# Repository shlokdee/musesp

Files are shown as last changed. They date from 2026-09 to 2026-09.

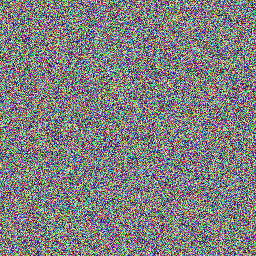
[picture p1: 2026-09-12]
firmware_platformio/musesp/sdcard/wokwi.bmp

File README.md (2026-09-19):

# Musesp: Portable Hi-Fi Digital Audio Player

**Musesp** is an open-source, ultra-portable Digital Audio Player (DAP) built on the ESP32-S3 microcontroller. It delivers high-resolution, uncompressed audio playback (FLAC/WAV) via an I2S DAC, featuring a 2.4" TFT graphical user interface and an isolated 3.0A power delivery system for low-noise audio performance.

---
### Inspiration
* Smartphones have thrown distraction free music listening out of the window, and i would like to bring it back into my life. I could've bought a ready made dap, but where is the fun in that. I have taken inspiration from various ipod restoration channels on youtube, but i wanna do it full DIY in my case.
---

## Technical Features

* **Lossless Audio Streaming:** Dual-core ESP32-S3 (240MHz, 8MB PSRAM) for continuous 24-bit/96kHz audio streaming.
* **Dedicated Hardware DAC:** PCM5102A DAC for clean IEM/headphone driving.
* **UI Navigation:** Hardware SPI ST7789 display paired with dynamic 5-button switch navigation (Play/Pause, Track Next/Prev, Volume +/-).
* **Onboard Storage:** Integrated MicroSD card slot utilization for fast FAT32/exFAT audio library parsing.

---
## Bill of Materials (BOM)

| Component | Description & Usecase | Qty | Unit Price (INR) | Total Price (INR) | Vendor Link |
| :--- | :--- | :---: | :---: | :---: | :--- |
| **ESP32-S3 DevKit (N16R8)** | Dual-core 240MHz MCU with integrated MicroSD slot, 8MB PSRAM & 16MB Flash. Handles audio buffering and display UI directly. | 1 | ₹839 | ₹839 | [Robu.in Link](https://robu.in/product/esp32-s3-devkit-esp32-s3-wroom-1-n16r8/) |
| **PCM5102A I2S DAC Module** | 32-bit / 384kHz Hi-Fi DAC with ~112dB SNR & integrated charge pump. Directly drives 16–32Ω IEMs via 3.5mm jack. | 1 | ₹450 | ₹450 | [Hubtronics Link](https://hubtronics.in/pcm5102-i2s-digital-audio-dac-decoder-module) |
| **2.4" SPI TFT Display (240x320)** | Full-color ST7789 SPI display for album art, track details, playback controls, and menu navigation. | 1 | ₹649 | ₹649 | [Robu.in Link](https://robu.in/product/2-4-inch-spi-interface-240x320-touch-screen-tft-display-module/) |
| **2 PIN WHITE TACT SWITCH C0402** | Switches for navigation and media controls (Play/Pause, Next, Prev, Vol+, Vol-). | 5 | ₹3 | ₹15 | [Robu.in Link](https://robu.in/product/2-pin-white-tact-switch-c0402/) |
| **NOVA 105050 3000mAh 3.7V LiPo Battery** | Single-cell 3.7V LiPo with onboard PCB protection. Delivers ~10–12 hours of continuous playback. | 1 | ₹469 | ₹469 | [Robu.in Link](https://robu.in/product/nova-105050-3000mah-3-7v-micro-lipo-battery-pack/) |
| **TP4056 1A Li-Ion Charger (Mini USB)** | Onboard 1A linear charging module with DW01 IC for over-charge, over-discharge, and short-circuit protection. | 1 | ₹38 | ₹38 | [Robu.in Link](https://robu.in/product/tp4056-1a-li-ion-lithium-battery-charging-module-with-current-protection-mini-usb/) |
| **SPDT Mini Slide Switch** | Physical hard toggle switch  | 1 | ₹12 | ₹12 | [Robu.in Link](https://robu.in/product-tag/slide-switch/) |
| **3D print** |-|-|₹500|₹500|Robu service|
| **Total Hardware Cost** | **Complete Portable Hi-Fi Player Hardware BOM** | - | — | **₹2972** | — |

31 USD

---

## Enclosure

The enclosure will be 3D printed. Also, this model is based on what models i find on the internet. Dimensions of various components may differ physically. This will be taken care of later.

[Onshape Model](https://cad.onshape.com/documents/264e94d89a18f09f2a1ea4bf/w/94a54fd68cc89b6b12089792/e/665c9b9603db8db9ac692859)
Screenshot From 2026-09-16 11-54-38

---
## Schematic


(sd card reader is included in the back of the devboard im using, so no connections for that...)



## Steps to Build:

1. Connect the components using the schematic
2. 3d Print the enclosure
3. Aligh the items using the onshape model given
4. Use 3 10 mm m3 screws to secure the back plate, and 1 3 mm m3 screw to secure the last hole on the display
5. Put the sd card with all your mp3 files
6. Flash the firmware from the platformio project
7. Youre done!!!

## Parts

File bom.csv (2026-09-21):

Component | Description & Usecase | Qty | Unit Price (INR) | Total Price (INR) | Vendor Link
ESP32-S3 DevKit (N16R8) | Dual-core 240MHz MCU with integrated MicroSD slot, 8MB PSRAM & 16MB Flash. Handles audio buffering and display UI directly. | 1 | ₹839 | ₹839 | https://robu.in/product/esp32-s3-devkit-esp32-s3-wroom-1-n16r8/
PCM5102A I2S DAC Module | 32-bit / 384kHz Hi-Fi DAC with ~112dB SNR & integrated charge pump. Directly drives 16–32Ω IEMs via 3.5mm jack. | 1 | ₹450 | ₹450 | https://hubtronics.in/pcm5102-i2s-digital-audio-dac-decoder-module
2.4" SPI TFT Display (240x320) | Full-color ST7789 SPI display for album art, track details, playback controls, and menu navigation. | 1 | ₹649 | ₹649 | https://robu.in/product/2-4-inch-spi-interface-240x320-touch-screen-tft-display-module/
2 PIN WHITE TACT SWITCH C0402 | Switches for navigation and media controls (Play/Pause, Next, Prev, Vol+, Vol-). | 5 | ₹3 | ₹15 | https://robu.in/product/2-pin-white-tact-switch-c0402/
NOVA 105050 3000mAh 3.7V LiPo Battery | Single-cell 3.7V LiPo with onboard PCB protection. Delivers ~10–12 hours of continuous playback. | 1 | ₹469 | ₹469 | https://robu.in/product/nova-105050-3000mah-3-7v-micro-lipo-battery-pack/
TP4056 Li-ion Battery Charger Module with Protection - Micro USB | Onboard 1A linear charging module with DW01 IC for over-charge, over-discharge, and short-circuit protection. | 1 | ₹19 | ₹19 | https://hubtronics.in/tp4056-dw01-fs8205
SPST Rocker switch | turning it on and off! | 1 | ₹14 | ₹14 | https://robu.in/product/spst-rocker-switch-pack-of-3/
3D printing case | - | - | ₹500 | ₹500 | "robu service"
Total Hardware Cost | Plus Shipping | 11 | — | 2955= 31 USD | —

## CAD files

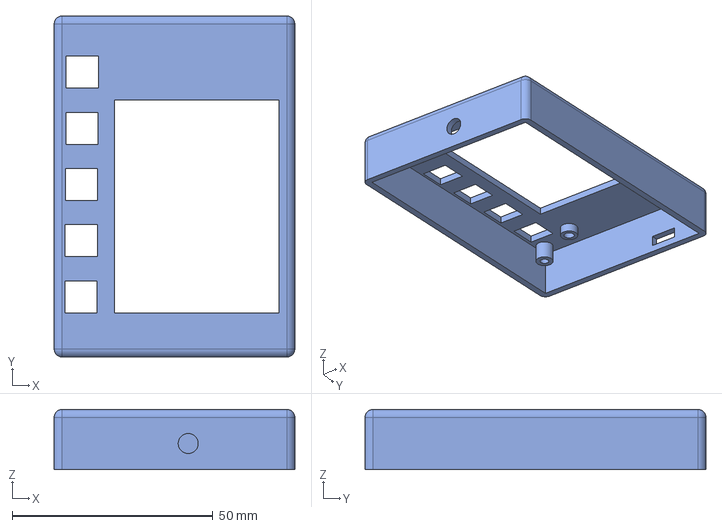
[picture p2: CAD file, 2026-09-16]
enclosure_files/frontplate.step
60.0 x 85.0 x 15.0 mm

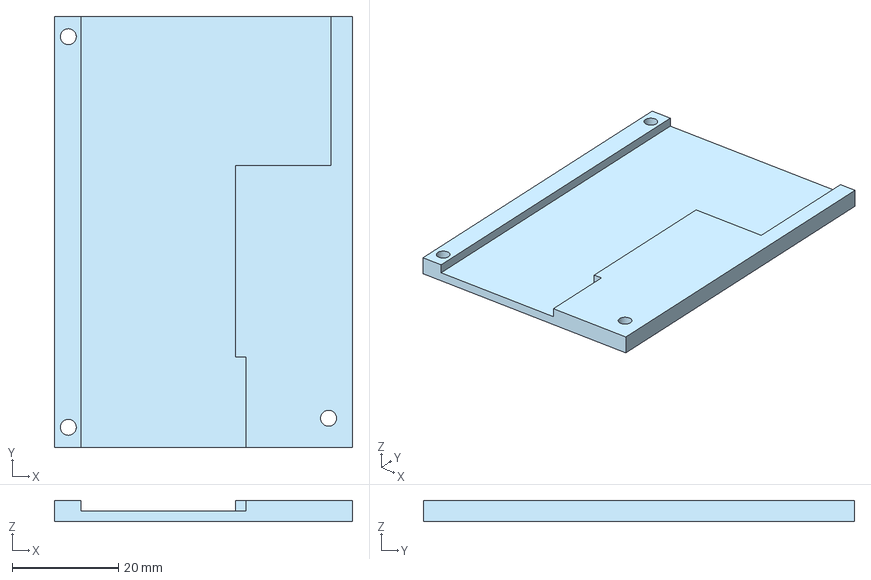
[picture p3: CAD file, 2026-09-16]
enclosure_files/Backplate.step
56.0 x 81.0 x 4.00 mm

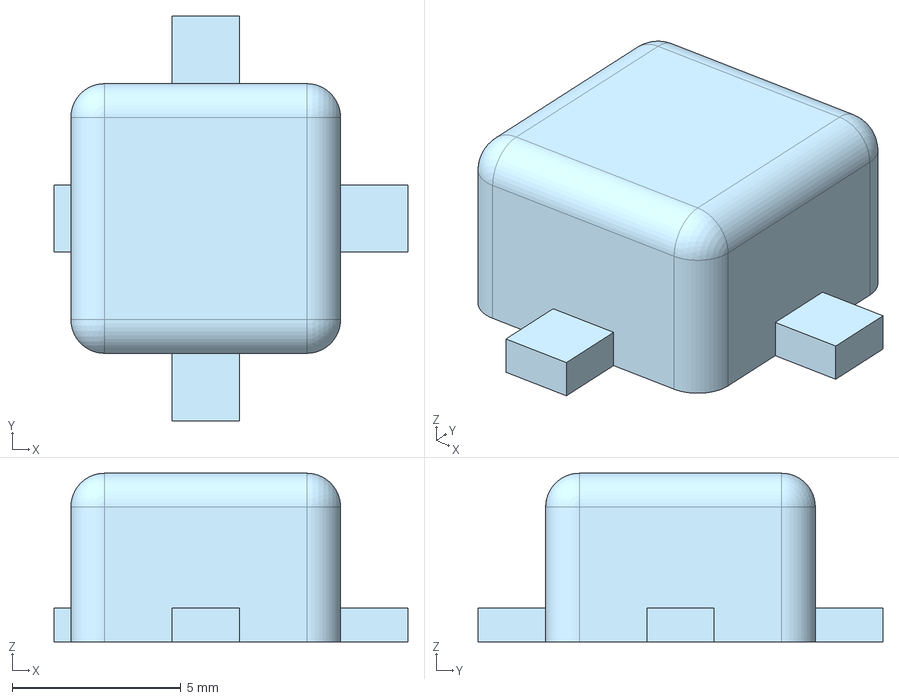
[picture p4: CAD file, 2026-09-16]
enclosure_files/button.step
10.5 x 12.0 x 5.00 mm

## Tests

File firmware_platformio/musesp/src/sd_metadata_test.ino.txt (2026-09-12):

#include "SdFat.h"

#define SPI_SPEED SD_SCK_MHZ(4)
#define CS_PIN 10

SdFat sd;

void readRealMP3Metadata(const char* filepath) {
  SdFile file;

  if (!file.open(filepath, O_READ)) {
    Serial.print("File not found on SD: ");
    Serial.println(filepath);
    return;
  }

  uint32_t fileSize = file.fileSize();
  Serial.println("----------------------------------------");
  Serial.print("File Path : "); Serial.println(filepath);
  Serial.print("File Size : "); Serial.print(fileSize); Serial.println(" bytes");

  // Check for ID3v2 header (first 10 bytes)
  char header[10];
  if (file.read((uint8_t*)header, 10) == 10) {
    if (strncmp(header, "ID3", 3) == 0) {
      Serial.print("Tag Format: ID3v2.");
      Serial.print((int)header[3]);
      Serial.print(".");
      Serial.println((int)header[4]);
    } else {
      Serial.println("Tag Format: No ID3v2 header at file start");
    }
  }

  // Check for ID3v1 footer (last 128 bytes)
  if (fileSize >= 128) {
    file.seekSet(fileSize - 128);
    char footer[128];
    if (file.read((uint8_t*)footer, 128) == 128) {
      if (strncmp(footer, "TAG", 3) == 0) {
        Serial.print("Title     : ");
        for (int i = 3; i < 33 && footer[i] != 0; i++) Serial.print(footer[i]);
        Serial.println();

        Serial.print("Artist    : ");
        for (int i = 33; i < 63 && footer[i] != 0; i++) Serial.print(footer[i]);
        Serial.println();
      } else {
        Serial.println("ID3v1     : No ID3v1 footer found");
      }
    }
  }

  file.close();
}

void setup() {
  Serial.begin(115200);
  while (!Serial) {}

  if (!sd.begin(CS_PIN, SPI_SPEED)) {
    Serial.println("SD card initialization failed!");
    return;
  }

  Serial.println("\n--- Current SD Card Directory ---");
  sd.ls(LS_R | LS_SIZE);

  Serial.println("\n--- Reading File Metadata ---");
  for (int i = 1; i <= 4; i++) {
    char path[32];
    snprintf(path, sizeof(path), "dummy_mp3s/track0%d.mp3", i);
    readRealMP3Metadata(path);
  }
}

void loop() {
}

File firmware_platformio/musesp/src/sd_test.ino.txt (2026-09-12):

#include "SdFat.h"

#define SPI_SPEED SD_SCK_MHZ(4)
#define CS_PIN 10

SdFat sd;
SdFile file;

void setup() {
  Serial.begin(115200);

  if (!sd.begin(CS_PIN, SPI_SPEED)) {
    Serial.println("SD initialization failed!");
    return;
  }

  // Open test.txt for writing (O_CREAT = create if missing, O_TRUNC = overwrite contents)
  if (!file.open("test.txt", O_WRITE | O_CREAT | O_TRUNC)) {
    Serial.println("Failed to open test.txt for writing!");
    return;
  }

  // Write multiple lines of data
  file.println("=== Wokwi SD Card Test File ===");
  for (int i = 1; i <= 10; i++) {
    file.print("Data Entry #");
    file.print(i);
    file.println(" -> Sensor reading: OK");
  }
  file.println("=== End of File ===");

  // Close the file to flush data to virtual storage
  file.close();
  Serial.println("Data successfully written to test.txt!\n");

  // Show directory listing
  Serial.println("Files currently on card:");
  sd.ls(LS_R | LS_SIZE);

  // Read back the contents to confirm
  Serial.println("\nReading test.txt contents back:");
  
}

void loop() {
}

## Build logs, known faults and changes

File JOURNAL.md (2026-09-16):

---
title: "musesp"
author: "f20260342"
description: "An audiophile digital audio player made with esp 32"
created_at: "2026-09-10"
---

# 2026-09-16: Completed the Design
**Total time spent: 30 mins** 
[Lapse Link](https://lapse.hackclub.com/timelapse/JOr6y3ShN6ii)

Finally completed the case design for the musesp...
### Designed the buttons

Designed the buttons and placed them in the assembly...

The button mounting is going to work as follows:
I will solder the buttons on a perf board and cut the perf board acc to the right dimensions. Then ill screw in the perf board in the holes on the front plate. Also, ill use a bigger screw, that goes through the backplate too, so that all of them are secured...


Thats what i did next. Added screw holes to the back plate and aligned them properly




And voila! The case is designed!!!

Next steps: Ship somewhere!!!

# 2026-09-14: Coded a bit more

**Total time spent: 1 hour 30 mins**

Added a bunch more logic to the code. 
First of all, i removed the delay thing, instead replaced it with millis. This will help when i write the music playing function, where i want to continuously play the music, delay wouldve caused gaps in between...



Then I also added what pausing would do. It pauses the whole thing as well as changes the icon. I had an issue where it would constantly refresh the icon every few milliseconds, but i solved it by adding a pause changed variable, which switches the icon every button press.

Then i added a debounce helper, as button pressing and the actions were unpredictable when i was testing it. a debounce helper basically notes only 1 button press down when you press it, or else the esp takes multiple presses per second if you keep holding it for more than a few ms... This also had caused the play button to just play for a few ms and then stop again, all in a single press. The debounce helper added a bit of margin to it.


# 2026-09-13: Simulated the switches and dummy tested the actions

**Total time spent: 1 hour**



Connected the switches in the simulator, and tested some code for the actions (fwd, bwd, pause, etc...) Still have to figure out the sd situation, thinking about writing some untested code that fetches from the sd card, populates a dictionary with the metadata... and then im trying to declare the dictionary as a variable in the code and write all the code based on that...

This is the loop i wrote that displays all the data (i still have to look at the image thing)
Also this delay thing wont work, as ill have to run other processes (like audio playback and list browsing) parallely. 

# 2026-09-13: Designed the case even better

**Total time spent: 1 hour**
[Lapse Link](https://lapse.hackclub.com/timelapse/mgQHt819XnAD)

I solved the fitting problem of the electronics components. I made a thick back plate, and then extrude cut the outlines of the boards... so that they sit into the surface... 

I will later add some clips to fasten the boards in place. But right now, the bards have somewhere to sit. Ive also given a but of snuggle room for the boards, as they can be different size from the ones i found step files of...



I also aligned and added holes for the charging port and 3.5 mm jack... I will probably add some finishing touches like a fillet and stuff, to make it less sharp. but its a later thing



Also adjusted the height so that it is really thin, as well as the clearances are met...
But, this is going to be adjusted later to make space for the battery... 



Im almost done with the design. i will continue with adding buttons later on, and also adding screws for the back plate to fit to the front plate...

The whole body is prolly too thick too, ill reduce the thickness for sure...

# 2026-09-13: Started designing the case

**Total time spent: 1 hour**
[Lapse Link](https://lapse.hackclub.com/timelapse/2ntoext6Lj6C)

I first tried to use fusion 360, but my laptop is slow as hell, so i switched to onshape...

I first downloaded a bunch of step files for the big 3, esp, lcd and the audio driver.


I also designed a face plate and added holes for buttons to pop up

Arranging them in the space was kinda tricky. firstly, the parts within the component had to be grouped, or else they werent moving together in the assembly. secondly, i couldnt remove the header pins of the display board, so the modules are kinda through the header pins, but ill fix it in real life...


Now i have to figure out the mounting thing, i can use bolts for the display and face plate, but something needs to be figured out for the esp and dac. 
Also battery needs to be included, along with carving the 3.5 mm jack and the charging port...

# 2026-09-12: Eureka moment with local wokwi

**Total time spent: 2 hours**

I forgot to Lapse this, but ive got a bunch of screenshots

### I got to know that i can use wokwi locally on vs code!!! 
this heavily reduces the compiling time....
but it took me a while to set up the whole thing...
* I had to install platformio first
* then create a project selecting the right board
* compile the code first, which generates firmware files
* then create a wokwi.toml file that i have to add the firmware file locations
* then copy paste the diagram.json from the online simulator
* then finally run the whole thing...


### Also remade the connections
Got to know that the board has some default spi pins, and the built in sd card is connected to those only...

So i revised the connections, and connected the display too to the same spi pins..

### Tried making the sd card work with vs code
Uploading files to sd card on online version was a premium feature, i thought it would be different here, but i couldnt figure out a way to do it...
I tried a bunch of different methods, like writing data first and then reading it back (this wouldve been just a temporary solution if worked...), making a folder called sd or sdcard and pray that wokwi would recognise it, etc... I didnt find anything on the docs either...



the sd was initialising, but file reading was not working....

# 2026-09-12: Designed the UI

**Total time spent: 1 hour**
[Lapse Link](https://lapse.hackclub.com/timelapse/PfEjHNs3jHrg)

I found this UI builder called lopaka

I used it to design a very basic UI, which was static. and then i can manipulate different stuff using the code... I built it so that its the only screen ill need to design. the songs will be listed in the right grid, and the now playing and buttons are there too....

Then i simulated it in wokwi, altering the lopaka code, and built a moving seeking bar. Ill still have to add some logic to move it according to the song length though.


# 2026-09-12: Simulated a very small part of the firmware

**Total time spent: 1.5 hours**
[Lapse Link](https://lapse.hackclub.com/timelapse/m9FCerOfpstV)

I thought Firmware design would be a piece of cake, ill just stitch together code from various sources and ill be done in a few hours...
but 1.5 hours in, im just done with displaying a small image from the sd to the display :cry:
So here is what i did today: 
### Test the display


I connected the display with the s3 according to the circuit i made yesterday, and started running example code from the libraries. Now the problem was that most of this code was written for Arduino. where the spi lanes area already decided. I didnt know if something like that was there for esp 32 as well. so i spent the fiarst 30 mins in figuring out that i have to declare the spi lanes myself. So i basically perfected the initialisation part, replaced the example code's display initialization with mine, and then run the example. 

I ran a few tests like text display, line display, image display, etc (i forgor to take a ss of this image display without sd card)..

### Test the sd card
Again i ran into problems with spi, and after a whole lot of figuring out, i got to know that you have to keep the same spi lanes for all spi devices. so i did that, and it started working. 


wokwi wont let me upload anything to the sd card, as uploading was a premium feature, so i instead replaced the wokwi's example code where they demonstrated displaying an image from the sd to display via arduino, with my code and circuitry. and it worked. 


I also uploaded the test codes and connections on github.

## Next steps: 
* Update the kicad with new connections
* Write firmware to read files from the sd card and put the album cover onto the display.
* Update the firmware to browse files from the sd card from the display
* Update the firmware to show the whole ui (now playing, control buttons, seeker, etc.)
* Design a case

# 2026-09-11: Figured out the Display and ESP connections using a simulator

**Total time spent: 1 hr**

I used Cirkit Designer IDE to connect, code and simulate the working of the Display with the esp 32 s3 board.



After this, i will start looking into the firmware for the display driving. 

# 2026-09-10: Added a readme and finished up with other small components

**Total time spent: 1 hour**

Made a readme, with project milestones, working plans. I believe moving ahead from here will require some breadboard prototyping, as im having really a hard time judging if things will work the way i want to. So ive decided to submit the project for review, if approved, get the components, try them together, and then move ahead with other stuff like software and enclosure. 
I also completed the bom for the first phase, with battery and charger. it comes out to around 26 usd. 


# 2026-09-10: Figured out the connections for the main 3 modules

**Total time spent: 1 hour**
[Lapse Link](https://lapse.hackclub.com/timelapse/I4MPxc_vWduY)

I looked around on the internet, read the seller specifications and laid out the basic connections for the 3 modules. The s3 variant of esp32 gave me a hard time. This is subject to change, as most of the reiterations on the hardware side is going to happen only after i receive the components. After that, i can actually test out the stuff and make changes. The schematic i made is kinda speculative, as most of the connections were for esp 32 and not s3. 


Next steps: Figure out the additional components, like battery management, buttons, etc. and build the case.

# 2026-09-10: Searched about various components required to build the project

**Total time spent: 2 hours**

I spent some time today researching the core hardware architecture for my portable Hi-Fi audio player, and preparing the basic BOM (essential components right now, others will be added later). The goal is to build an iPod-style player capable of driving sensitive In-Ear Monitors (IEMs) with zero noise or hiss, playing lossless files (WAV/FLAC), and maintaining a fully modular design so components can be swapped out easily.

### Key Decisions & Hardware Reasoning

- **Microcontroller: ESP32-S3 (with PSRAM)**
    
    - _Why:_ Standard microcontrollers like an Arduino Uno dont have the processing power or hardware peripherals for real-time audio decoding. The ESP32 offers native I2S bus support, dual-core processing, and built-in Wi-Fi/Bluetooth. Using an ESP32-S3 with external PSRAM gives the large RAM buffer needed to stream 16-bit/24-bit FLAC files off an SD card without playback stutter as well as render the album art properly. Also the one i put in the BOM has a SD card slot as well.
        

- **DAC Module: TI PCM5102A (Over UDA1334A or MAX98357A)**
    
    - _Why:_ IEMs are extremely sensitive to background hiss. The other dac modules i looked at were either too high powered, or too low quality
        

- **Display: ST7789 2.0"/2.4" SPI TFT LCD (240x320)**
    
    - _Why:_ Other OLEDs (like the SSD1306) are too small to render track lists and album art nicely. This is perfectly sized, works over SPI.
      

### What's Next?

Now that the hardware strategy is locked in, Im going to start looking at connections and start building the basic 3d structure of the player. Im also going to add other components like battery, charging circuit, etc to the BOM

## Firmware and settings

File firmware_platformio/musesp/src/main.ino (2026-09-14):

#include <SPI.h>
#include <FS.h>
#include <SD.h>

#include <Adafruit_GFX.h>
#include <Adafruit_ILI9341.h>
#include "ui.h"
#include "debounce_helper.h"
#include "audio_player.h"


// ESP32-S3 to ILI9341 wiring in this project
#define TFT_CS 9


#define TFT_DC 15
#define SD_CS 10

#define up_btn 42
#define down_btn 41
#define fback_btn 40
#define pause_btn 39
#define ffront_btn 38

Button btnUp    = {up_btn};
Button btnDown  = {down_btn};
Button btnBack  = {fback_btn};
Button btnPause = {pause_btn};
Button btnFwd   = {ffront_btn};

Adafruit_ILI9341 tft(TFT_CS, TFT_DC, -1);



String randomSongs[] = {
    "Blinding Lights", "Pasoori", "Shape of You", "Jai Ho", 
    "As It Was", "Kahani Suno", "Levitating", "Tum Se Hi", 
    "Starboy", "Apna Bana Le", "Flowers"
};

String randomArtists[] = {
    "The Weeknd", "Ali Sethi", "Ed Sheeran", "A.R. Rahman", 
    "Harry Styles", "Kaifi Khalil", "Dua Lipa", "Mohit Chauhan", 
    "The Weeknd", "Arijit Singh", "Miley Cyrus"
};

int randomTimes[] = {
    20000, 35000, 15000, 40000, 
    25000, 30000, 20000, 45000, 
    30000, 15000, 25000
};

String randomfiles[] = {
    "/blinding_lights.mp3", "/pasoori.mp3", "/shape_of_you.mp3", "/jai_ho.mp3", 
    "/as_it_was.mp3", "/kahani_suno.mp3", "/levitating.mp3", "/tum_se_hi.mp3", 
    "/starboy.mp3", "/apna_bana_le.mp3", "/flowers.mp3"
};
void setup() {
  Serial.begin(115200);
  delay(100);

  pinMode(TFT_DC, OUTPUT);
  pinMode(TFT_CS, OUTPUT);
digitalWrite(TFT_CS, HIGH);
pinMode(SD_CS, OUTPUT);
digitalWrite(SD_CS, HIGH);

pinMode(up_btn, INPUT_PULLUP); 
pinMode(down_btn, INPUT_PULLUP);
pinMode(fback_btn, INPUT_PULLUP);
pinMode(pause_btn, INPUT_PULLUP);
pinMode(ffront_btn, INPUT_PULLUP);
    
  tft.begin();
  setupAudio();


  if (!SD.begin(SD_CS, SPI, 10000000)) {
    Serial.println(F("SD begin() failed"));
    for (;;);
  }
    Serial.println("SD Card initialized.");


drawScreen_landscape(tft);


}
int divisions= 96;
int i=0;
bool paused=true;
bool pauseChanged = false;
int stepNum=0;
bool songChanged=true;
unsigned long lastTimer=0;


void loop(void) {
audio.loop();
  if (pressed(btnPause)) {
    paused = !paused;
    pauseChanged = true;
    audio.pauseResume();
  }

  if (pressed(btnFwd)) {
    i++;
    if (i >= sizeof(randomSongs)/sizeof(randomSongs[0])) i = 0;
    stepNum = 0;
    songChanged = true;
  }
else if (pressed(btnBack)) {
    i--;
    if (i < 0) i = 0;
    stepNum = 0;
    songChanged = true;
  }

  if (songChanged) {
    drawText_landscape(tft, randomSongs[i], randomArtists[i]);
    playSong(randomfiles[i]);
    songChanged = false;
  }

if (pauseChanged) {
    drawPause_landscape(tft, paused);
    pauseChanged = false;
  }

  if (paused) {
    return;
  }

  

  int stepdelay = randomTimes[i] / divisions;
  if (millis() - lastTimer >= stepdelay) {
    lastTimer = millis();
    tft.fillRect(202, 188, stepNum, 11, 0xFFFF);
    stepNum++;
    if (stepNum > divisions) {
      stepNum = 0;
      i++;
      if (i >= sizeof(randomSongs)/sizeof(randomSongs[0])) i = 0;
      songChanged = true;
    }
}
}

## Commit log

2026-09-10 created bom for project
    Added a bill of materials (BOM) with components, descriptions, quantities, prices, and vendor links.
2026-09-10 updated the bom
2026-09-10 updated bom
2026-09-10 Enhance README with project details and milestones
    Expanded the README to include detailed project description, technical features, bill of materials, enclosure roadmap, and development milestones.
2026-09-10 basic schematic
    [musesp.kicad_sch]
2026-09-13 Revise enclosure details and add images
    Updated enclosure section with additional details and images.
2026-09-16 Convert BOM from markdown to CSV format
    Updated BOM from markdown format to CSV format, preserving component details and pricing.
    [bom.csv]
2026-09-16 Update total hardware cost in BOM file
    [bom.csv]
2026-09-16 updated schematic
    [musesp.kicad_sch]
2026-09-16 added step files
    [Backplate.step, button.step, front plate.step]
2026-09-21 Modify bom.csv to update components and costs
    Updated component list and adjusted total hardware cost.
    [bom.csv]
